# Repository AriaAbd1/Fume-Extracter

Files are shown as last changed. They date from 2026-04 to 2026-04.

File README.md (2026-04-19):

# DIY High-Performance Fume Extractor

A professional-grade, portable DIY fume extractor designed for electronics soldering and small-scale 3D printing. This project features a high-static-pressure PC fan, PWM speed control, and a "plug and play" DC power design.

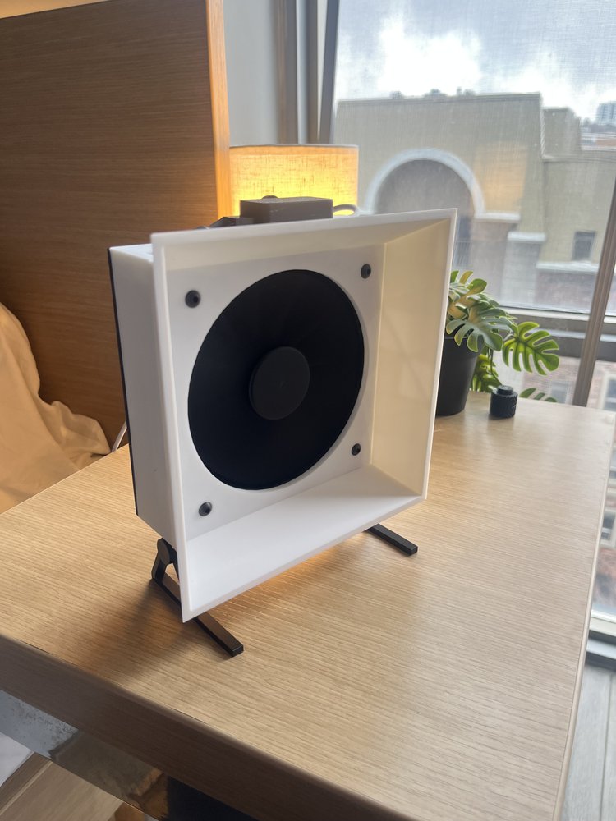
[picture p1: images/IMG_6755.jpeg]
Fume Extractor Overview


## Features

- **High Airflow & Static Pressure**: Utilizes a Noctua 120mm industrial-grade PC fan for efficient smoke capture.
- **Variable Speed Control**: Integrated PWM controller for precise airflow management and noise reduction.
- **Modular Filtering**: Easy-access filter slot for activated carbon sheets.
- **Rugged 3D Printed Housing**: High-precision housing printed on an **Elegoo Centauri Carbon** in PLA.
- **Adjustable Tilt**: Integrated pivot rod for optimal positioning.

## Technical Specifications

| Parameter | Specification |
|---|---|
| Input Voltage | 12V - 24V DC (Plug & Play) |
| Fan Size | 120mm x 120mm x 25mm |
| Control Type | PWM rated for 0.5-0.7A |
| Current Draw | 0.3A |
| Filter Type | Activated Carbon |

## Component List (BOM)

- **Fan**: [Noctua NF-F12 industrialPPC-24V-3000 IP67 PWM](https://www.amazon.ca/dp/B00KFCRATC). High-performance industrial fan.
- **Control**: [Mini DC Motor PWM Speed Controller](https://www.aliexpress.com/item/1005007648380753.html) (3V-35V 5A).
- **Filter**: [Activated Carbon Filter Sheets](https://www.amazon.ca/dp/B07RNGMXYG) (130x130mm).
- **Hardware**: McMaster-Carr stainless steel screws and nuts (See [BOM](docs/BOM.md)).
- **Housing**: 3D Printed PLA parts.

## Manufacturing & 3D Printing

The housing components are designed for high durability and ease of assembly.

- **Printer**: Centauri Carbon Elegoo
- **Material**: PLA
- **Settings**: Varying per part. See documentation for more details. 

## Repository Structure

- `cad/`: 3D design files 
- `images/`: Project builds, assembly photos, and test parts.
- `docs/`: Technical manuals, [BOM](docs/BOM.md), and [Assembly Guide](docs/Assembly.md).

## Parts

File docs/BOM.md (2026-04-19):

# Bill of Materials (BOM)

| Item | Qty | Link/Notes |
|---|-----|---|
| Neodymium Magnets (0.12x0.04 in) | 8 | [Amazon.ca](https://www.amazon.ca/Neodymium-Magnets-Different-Whiteboard-Miniatures/dp/B0C9GLYGDR) |
| Noctua NF-F12 industrialPPC-24V-3000 | 1 | [High-Performance 24V Fan](https://www.amazon.ca/dp/B00KFCRATC) |
| Mini DC PWM Speed Controller | 1 | [3V-35V 5A Controller](https://www.aliexpress.com/item/1005007648380753.html) |
| Activated Carbon Filter Sheets | 1 | [Carbon Filter](https://www.amazon.ca/dp/B07RNGMXYG) |
| 3D Printed Housing (PLA) | 1 | Printed on Centauri Carbon Elegoo |
| Button Head Hex Drive Screw (M4 x 50mm) | 4 | [McMaster 91239A162](https://www.mcmaster.com/91239A162/) |
| Thin-Profile Square Nuts (M4) | 6 | [McMaster 97258A124](https://www.mcmaster.com/97258A124/) |
| Flat-Tip Set Screw (M4 x 8mm) | 2 | [McMaster 92605A113](https://www.mcmaster.com/92605A113/) |
| Steel Pivot Rod | 1 | Structural pivot for housing |

## Assembly Notes

1. **Power**: This build is powered via a direct DC input (12V-24V) into the PWM controller.
2. **Control**: The Noctua 24V fan is controlled via the PWM dial on the speed controller.
3. **Mounting**: Use the 50mm button head screws and square nuts to secure the fan and housing.
4. **Pivot**: The steel rod serves as the main pivot for the adjustable housing.

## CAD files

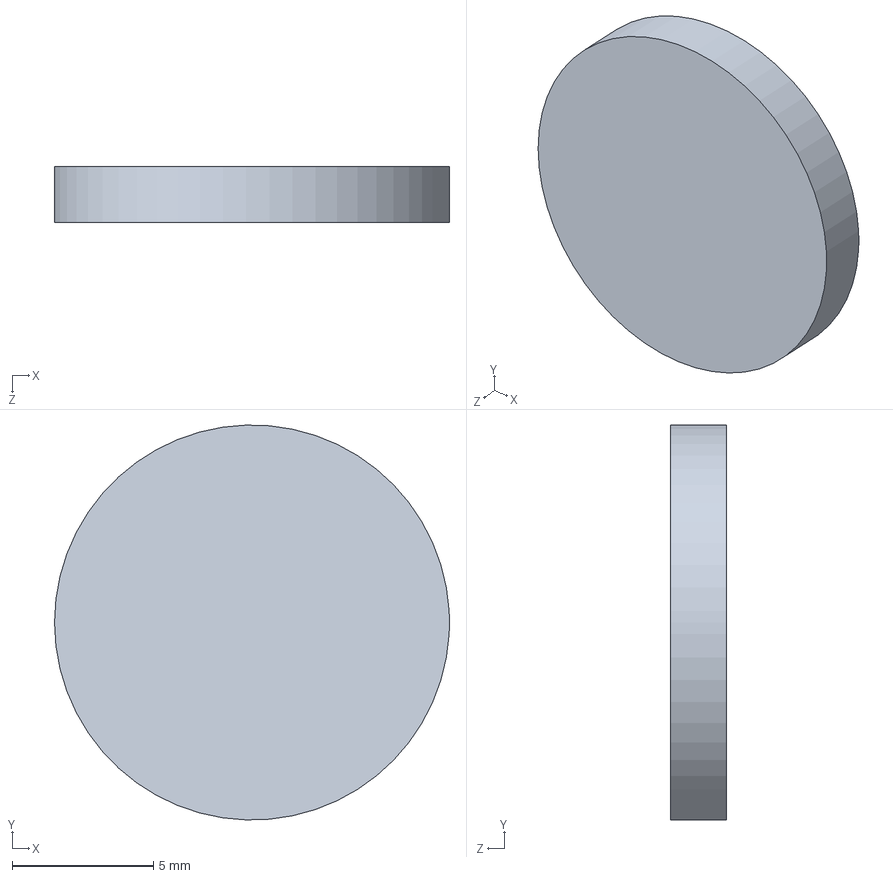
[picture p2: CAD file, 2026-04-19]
CAD files/Pivot_Rod_Caps.SLDPRT
14.0 x 14.0 x 2.00 mm

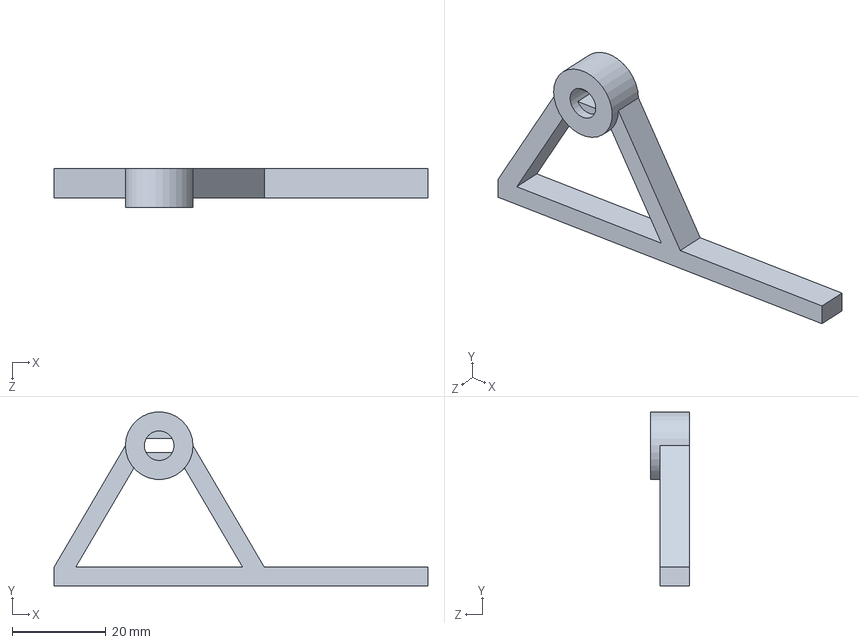
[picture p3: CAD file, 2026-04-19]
CAD files/Base_Stand_Standard.SLDPRT
80.0 x 37.2 x 8.30 mm

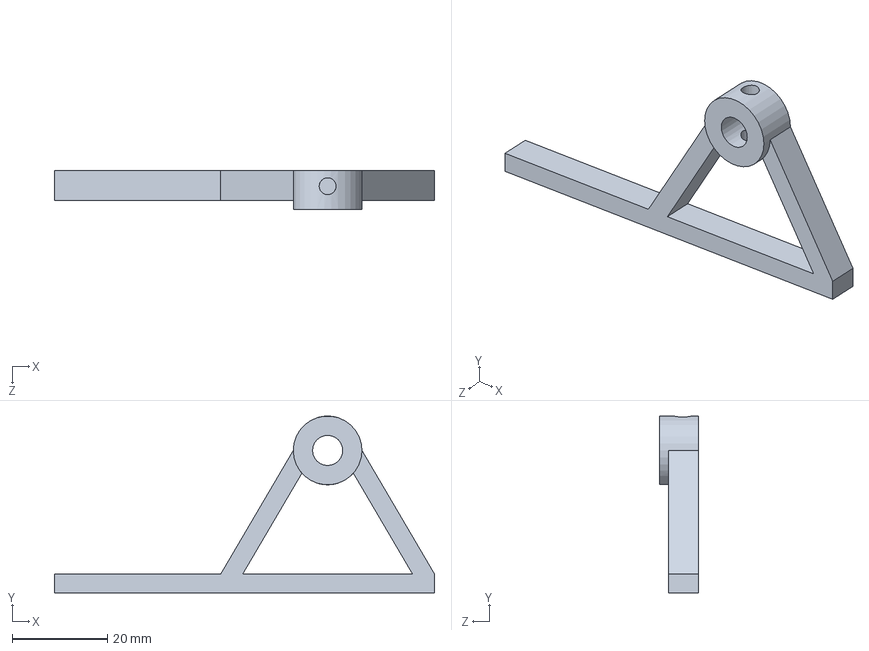
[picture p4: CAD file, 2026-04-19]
CAD files/Base_Stand_Dowel_Mount.SLDPRT
80.0 x 37.2 x 8.30 mm

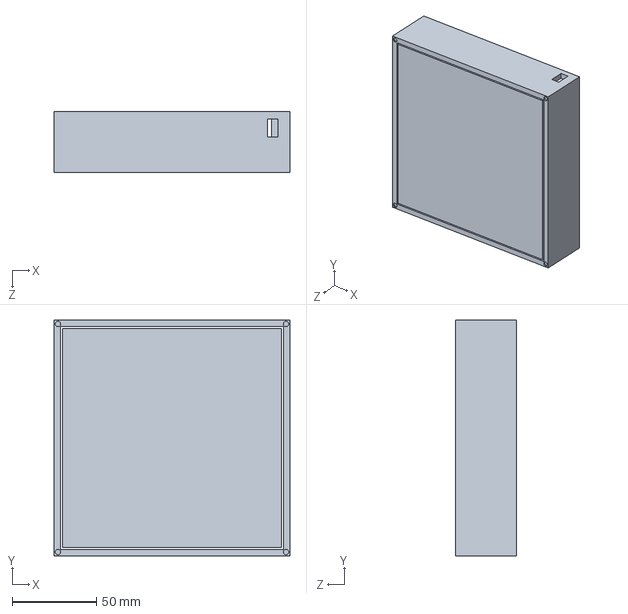
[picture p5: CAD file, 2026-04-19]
CAD files/Housing_Walls.SLDPRT
140.0 x 140.0 x 36.0 mm

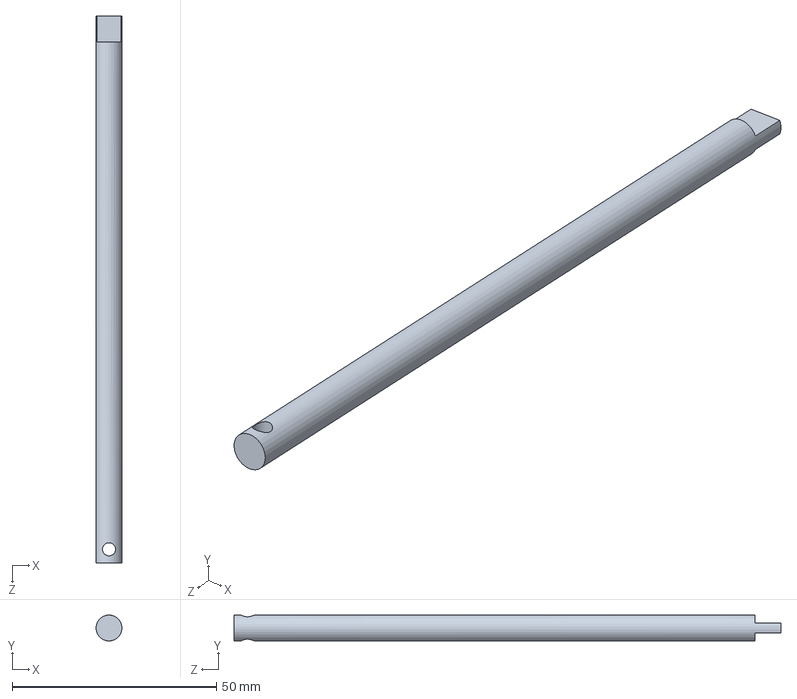
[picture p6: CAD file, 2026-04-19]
CAD files/Pivot_Rod.SLDPRT
6.35 x 6.35 x 134.0 mm

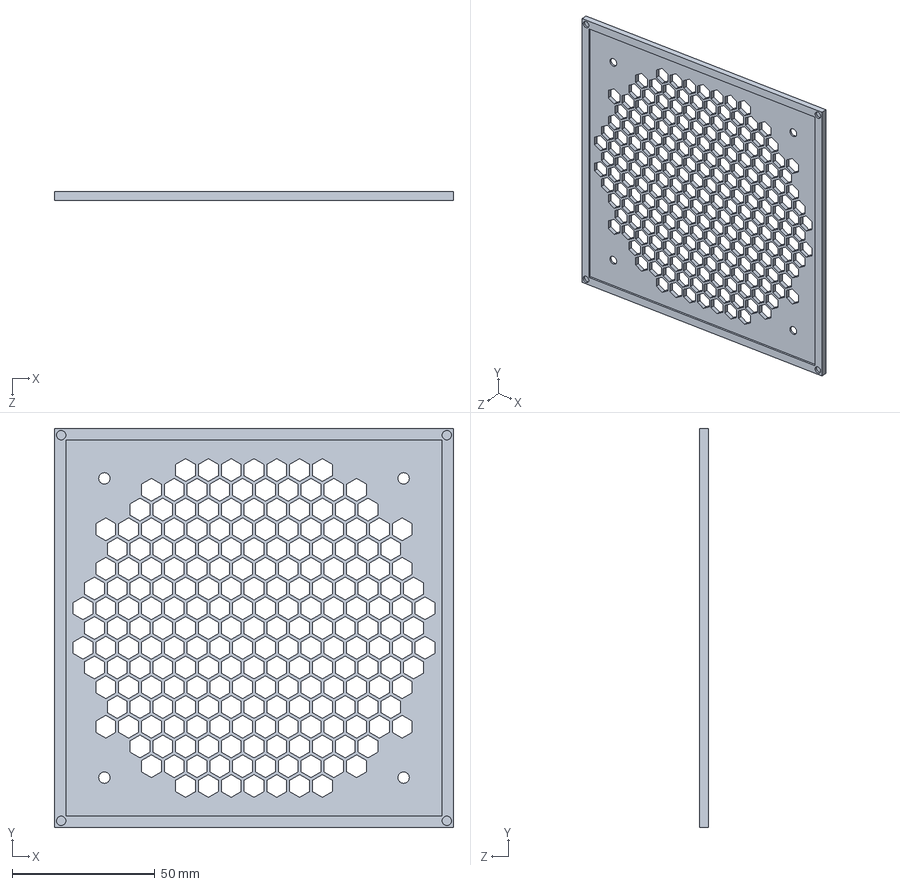
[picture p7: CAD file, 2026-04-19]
CAD files/Backside_Mesh.SLDPRT
140.0 x 140.0 x 3.00 mm

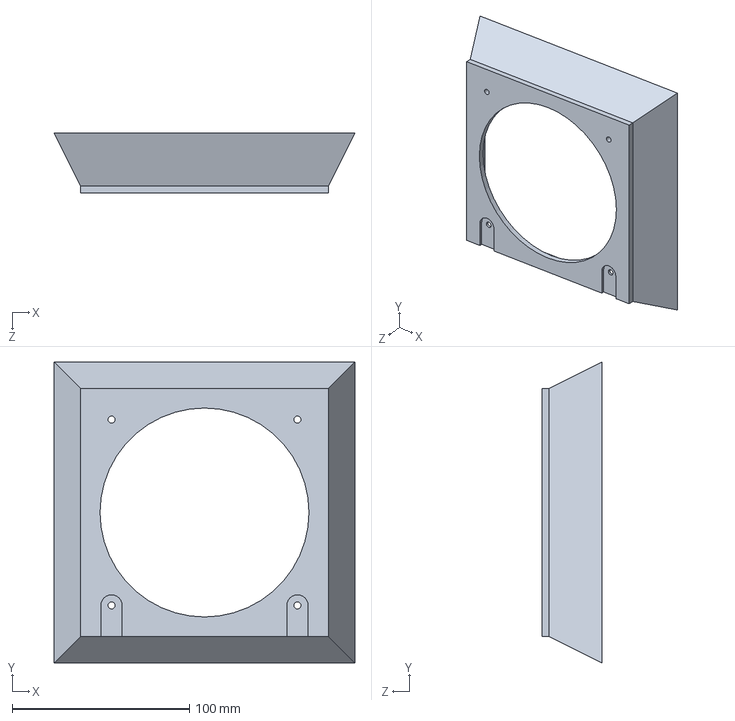
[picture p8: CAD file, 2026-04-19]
CAD files/Front_Housing.SLDPRT
170.0 x 170.0 x 34.0 mm

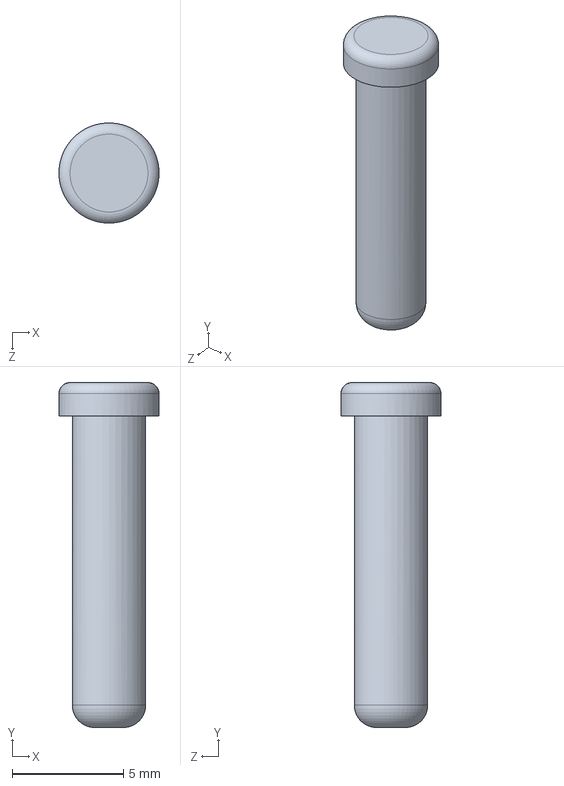
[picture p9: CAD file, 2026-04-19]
CAD files/Stand_Dowel.SLDPRT
4.50 x 15.5 x 4.50 mm

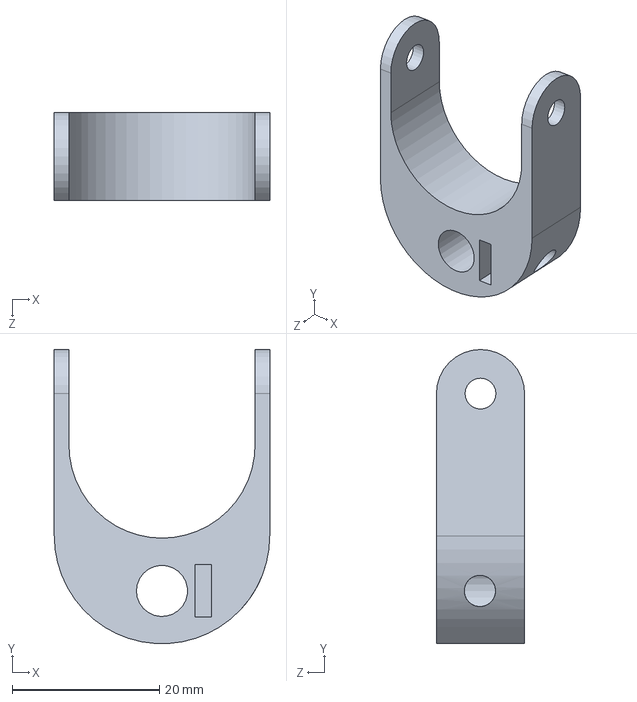
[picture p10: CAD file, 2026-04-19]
CAD files/Pivot_Mount.SLDPRT
29.3 x 40.0 x 12.0 mm

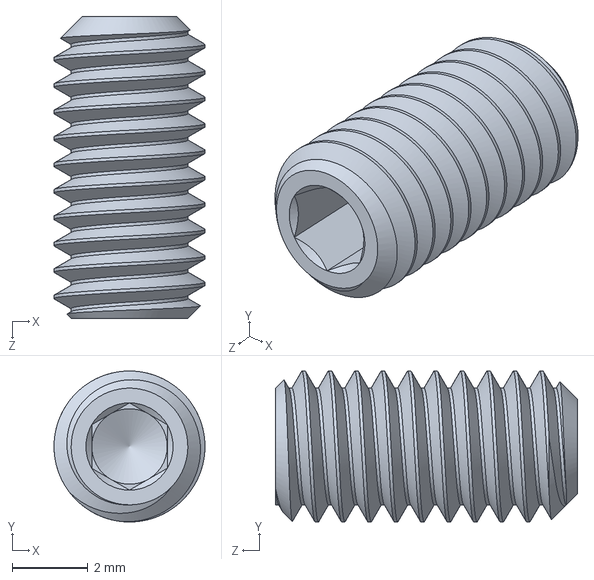
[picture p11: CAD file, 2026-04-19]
CAD files/92605A113_Stainless Steel Flat-Tip Set Screw.SLDPRT
4.00 x 4.00 x 8.00 mm

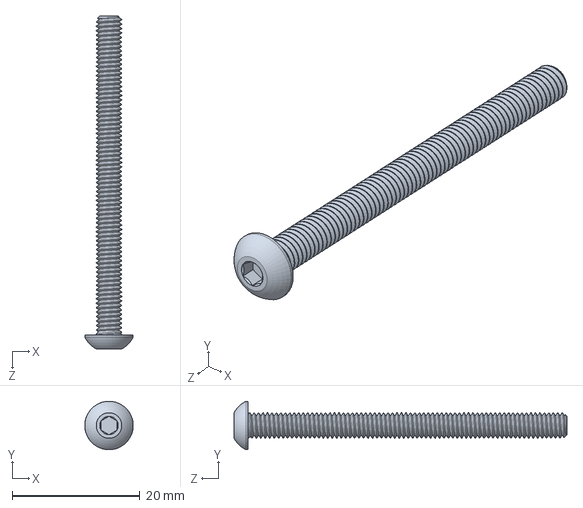
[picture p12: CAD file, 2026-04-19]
CAD files/91239A162_Button Head Hex Drive Screw.SLDPRT
7.60 x 7.60 x 52.2 mm

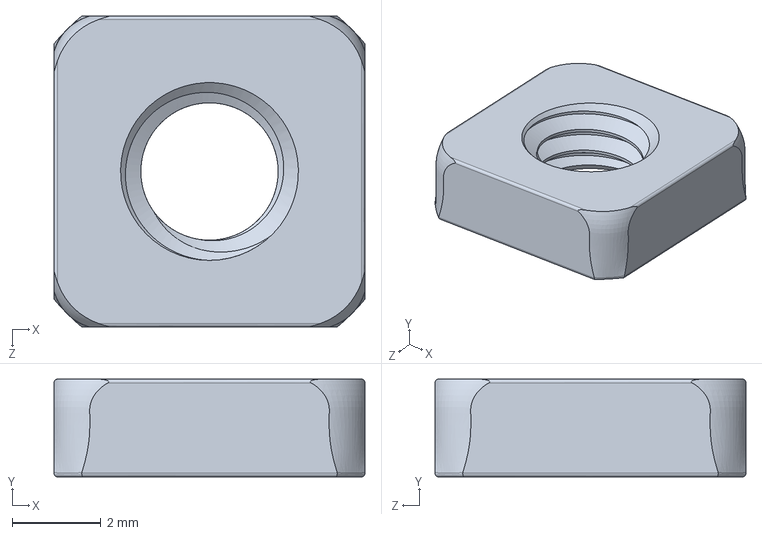
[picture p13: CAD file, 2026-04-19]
CAD files/97258A124_18-8 Stainless Steel Thin-Profile Square Nuts.SLDPRT
7.00 x 2.20 x 7.00 mm

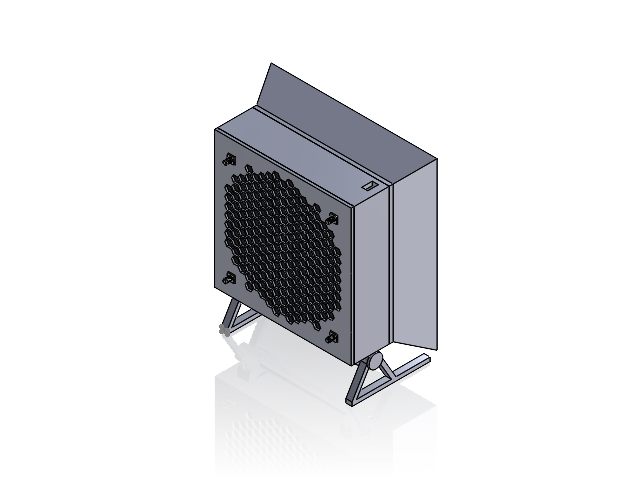
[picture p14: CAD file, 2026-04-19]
CAD files/Fume_Extractor_Assembly.SLDASM
Fume_extruder_Frame
Swivel mount x 2
Frame base
91239A162_Button Head Hex Drive Screw x 4
Metal pivot rod
FIlter Mesh Frame
97258A124_18-8 Stainless Steel Thin-Profile Square Nuts x 6
stand_no_peg
stand_with_peg
caps x 2
dowel
92605A113_Stainless Steel Flat-Tip Set Screw x 2

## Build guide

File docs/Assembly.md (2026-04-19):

# Assembly Guide

Follow these steps to assemble your DIY Fume Extractor.

## Tools Required
- Two small Allen keys (smallest sizes for M4 screws and set screws)
- Gorilla Super Glue (cyanoacrylate glue); optional: fast-setting spray/accelerator
- Needle-nose pliers 

## Step 1: Pivot Mount Preparation
- Firmly press-fit the thin-profile square nuts into the `Pivot_Mount` pieces. Use needle-nose pliers to push them in all the way—it is a very tight fit.
- Insert the flat-tip set screws so the nuts don't fall out, but leave the central rod hole completely clear for the pivot rod to pass through.
- Make sure that the set screws on both mounts face the same direction—facing away from where the base stands' forward protrusions will be.

## Step 2: Base Assembly Setup
- Attach the `Pivot_Rod` to the `Base_Stand_Standard` (the stand without a peg hole).
- Slide both `Pivot_Mount` pieces onto the rod. 
- Attach the `Pivot_Rod` into the other stand, the `Base_Stand_Dowel_Mount`.
- Insert the `Stand_Dowel` peg into the mount's hole to lock the rod. This should be a tight friction-fit.

## Step 3: Fan & Front Housing
- Remove the front silicone anti-vibration pads from the Noctua fan.
- **Important:** Route the fan cable around the fan frame (going around 3 corners) before installing the mounts. Doing this now ensures you won't have to disassemble and rebuild the unit later because of improper routing.
- Place the fan into the `Pivot_Mount` pieces, lining up the fan's screw holes with the ones on the mounts.
- Place the pivot mounts into their respective grooves on the interior of the `Front_Housing`.
- Insert the four long M4 x 50mm Button Head Hex screws from the front outside face of the `Front_Housing`. Drive them through all the holes, but only enough so that they stick out from the back of the assembly by just 1-2 cm.

## Step 4: Cable Routing & Housing Walls
- Ensure the fan cable is snug against the fan and comes out the "top" of the `Front_Housing` with about 5 cm sticking out.
- With the cable in position, slide the cable header through the rectangular hole on the `Housing_Walls` and pull it through. 
- Lower the `Housing_Walls` down until they match the edges of the `Front_Housing`.
- Secure the walls to the front housing with Gorilla superglue. **Do not spray accelerant on this**, as it may ruin the white finish of the plastic! Ideally, apply glue inside at the contact points, but exterior gluing is fine too. You only need to fully glue 2 or 3 sides. 
- Ensure that the fan cable sticks out from the top, directly opposite to the base assembly pointing at the bottom.

## Step 5: Filter & Backside Mesh
- Lay the assembly flat on its face (front housing pointing down).
- *(Optional)* Place a small dab of super glue on the underside of the magnets before inserting them into their grooves on the `Housing_Walls` and the `Backside_Mesh`. They are not 100% friction fit, and the magnetic force can easily pull them out if they are unglued. Ensure polarities match so they attract!
- Place the activated carbon filter into the backside, letting the 1-2 cm exposed screw tips punch holes through the filter material.
- Place the `Backside_Mesh` onto the walls. The magnets will help snap it into alignment and keep it in place.

## Step 6: Securing the Enclosure
- Place the flat thin-profile square nuts into the grooves on the `Backside_Mesh`.
- One by one, screw the long M4 x 50mm screws all the way through until the nut is secure. Stop tightening when secure; do not over-tighten, or the back mesh will warp from the screw tension.

## Step 7: Final Base Assembly
- Apply glue to the outer-facing sides of the base stands (where the pivot rod is exposed).
- Place the `Pivot_Rod_Caps` on concentrically with the rod to finish the look.

## Step 8: Electronics & Final Adjustments
- Find an arbitrary but convenient location on the outside surface of the `Housing_Walls`—ideally where it's easy to remove the cables and control the dial—and glue the PWM controller module down.
- Attach the fan cable to the PWM controller module.
- Adjust the fan housing to your preferred upright angle, then tighten the set screws on the `Pivot_Mount` pieces to lock the whole thing in position.
- Finally, plug a USB-C power cable into the PWM module, turn the dial to set your fan speed, and the assembly is complete!

## Safety Precautions
- **Clearance Check:** Before plugging in the fan controller, verify all parts are securely mounted and that the fan blades are unobstructed. The fan operates at a high RPM and can cause significant injury to skin or soft tissues if contacted while spinning.
- **Cable Management:** Ensure the cable is not under tension and cannot touch the fan blades. Proper routing prevents cable damage and ensures long-term reliability.

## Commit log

2026-03-25 Initial commit: Professional Fume Extractor Project Setup
    [120mm-Fan-Mount-Grill-With-Locator-Tabs.stl, 120mm-Fan-Mount-Mount-Base.stl]
2026-03-25 Update hardware specs, create assembly guide, and remove CAD files
    [120mm-Fan-Mount-Grill-With-Locator-Tabs.stl, 120mm-Fan-Mount-Mount-Base.stl]
2026-03-25 Remove remaining battery mentions from README
2026-03-25 Revise filter dimensions and printing settings
    Updated filter size and manufacturing settings in README.
2026-03-25 Update fan control type and current draw specifications
2026-03-26 Remove portfolio-specific assembly gallery from README
2026-04-19 Update assembly, CAD files, and add new photos
    [91239A162_Button Head Hex Drive Screw.SLDPRT, 92605A113_Stainless Steel Flat-Tip Set Screw.SLDPRT, 97258A124_18-8 Stainless Steel Thin-Profile Square Nuts.SLDP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]
2026-04-19 Update magnet quantity in BOM
